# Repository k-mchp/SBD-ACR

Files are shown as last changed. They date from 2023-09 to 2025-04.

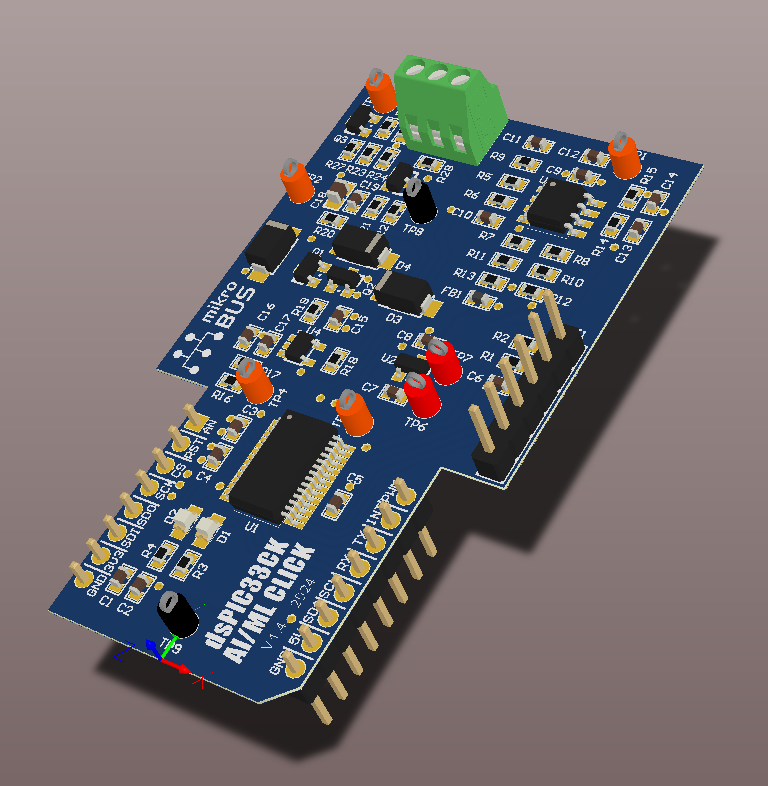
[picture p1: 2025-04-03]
PCB-Battery-click/Altium/3D Image of PCB.PNG

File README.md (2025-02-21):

#Battery Impedance Measurement Project / AC Internal Resistance
This repo contains SW flow chart and source code for Lithium Ion battery Impedance measurement project

-ACR Firmware Flow.pdf
  PDF form of current SW flow chart
  (current version = 1.2)
  
-ACR Firmware Flow.vsdx
   Visio format file of current SW flow chart
   (current version = 1.2)
   
-ACR_8-5-source.zip
  Compressed folder of MPLAB project Source code and data spreadsheet
  
-AIML-motors1
  PDF to show next step implementation of AIML control of motor to be driven by the Battery

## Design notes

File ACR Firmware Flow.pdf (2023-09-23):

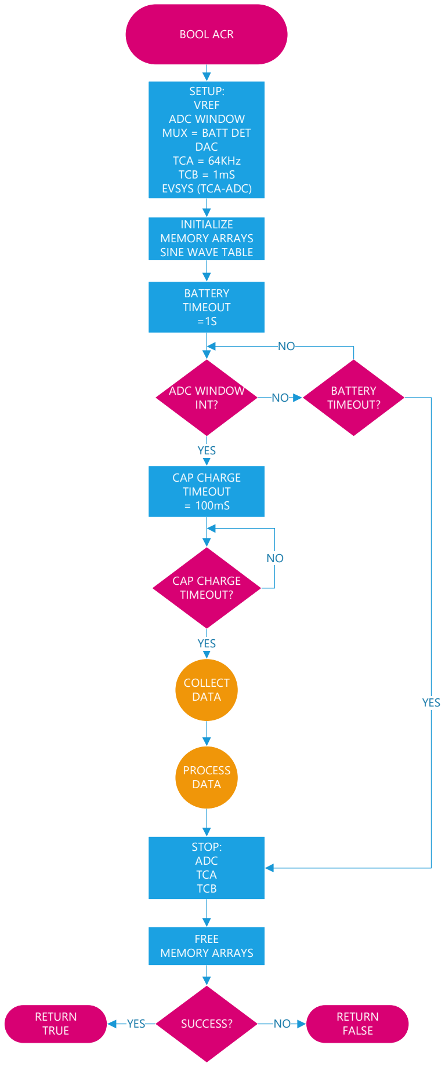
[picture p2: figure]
BOOL ACR; SETUP: VREF ADC WINDOW MUX = BATT DET DAC TCA = 64KHz TCB = 1mS EVSYS (TCA-ADC); INITIALIZE MEMORY ARRAYS SINE WAVE TABLE; BATTERY TIMEOUT =1S; ADC WINDOW INT?; SUCCESS?; RETURN; FALSE; TRUE; YES; CAP CHARGE TIMEOUT = 100mS; BATTERY TIMEOUT? NO; STOP: ADC TCA TCB; FREE MEMORY ARRAYS; CAP CHARGE TIMEOUT?; COLLECT DATA; PROCESS DATA
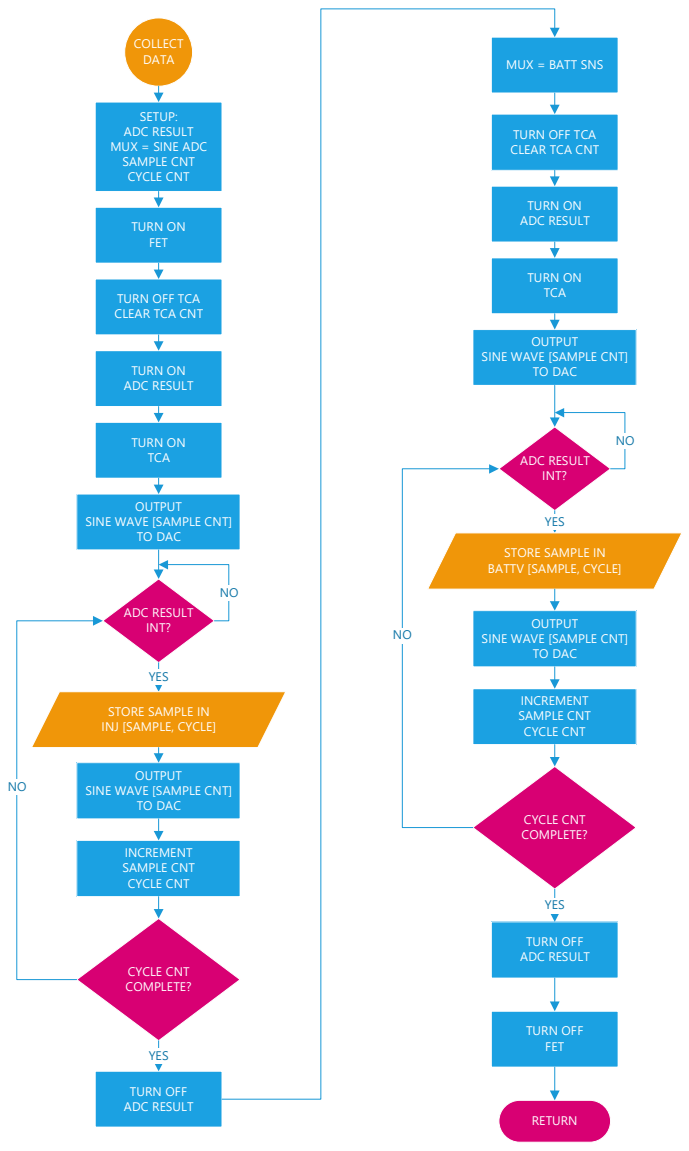
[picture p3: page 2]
COLLECT DATA; TURN ON ADC RESULT; CYCLE CNT COMPLETE?; TURN ON TCA; OUTPUT; TO DAC; TURN OFF ADC RESULT; TURN ON FET; ADC RESULT INT?; YES

MUX = BATT SNS

SETUP:
ADC RESULT
MUX = SINE ADC
SAMPLE CNT
CYCLE CNT

TURN OFF TCA
CLEAR TCA CNT

SINE WAVE [SAMPLE CNT]

STORE SAMPLE IN
BATTV [SAMPLE, CYCLE]

SINE WAVE [SAMPLE CNT] | OUTPUT TO DAC

YES

INCREMENT SAMPLE CNT CYCLE CNT

INJ [SAMPLE, CYCLE]

TURN OFF FET

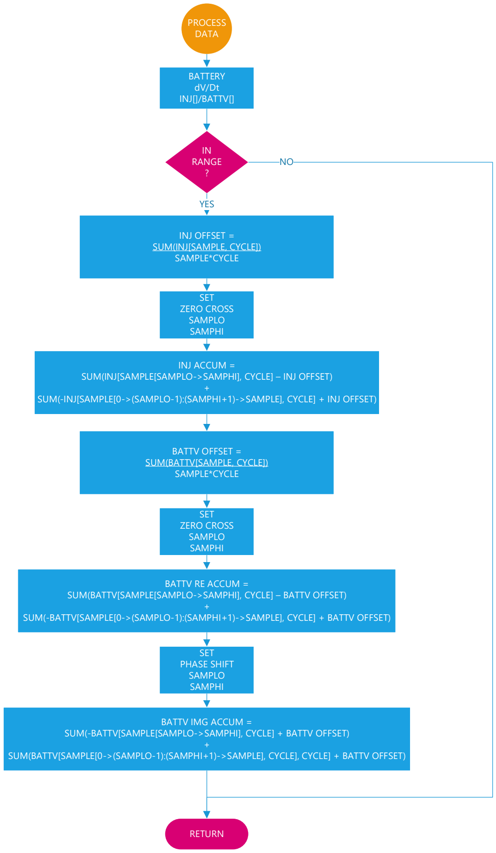
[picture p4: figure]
PROCESS DATA; BATTERY dV/Dt INJ[]/BATTV[]; IN RANGE ?; INJ OFFSET = SUM(INJ[SAMPLE, CYCLE]) SAMPLE*CYCLE; INJ ACCUM = SUM(INJ[SAMPLE[SAMPLO->SAMPHI], CYCLE] – INJ OFFSET) + SUM(-INJ[SAMPLE[0->(SAMPLO-1):(SAMPHI+1)->SAMPLE], CYCLE] + INJ OFFSET); BATTV OFFSET = SUM(BATTV[SAMPLE, CYCLE]) SAMPLE*CYCLE; BATTV RE; ACCUM =; SUM(BATTV[SAMPLE[SAMPLO->SAMPHI], CYCLE] – BATTV OFFSET) + SUM(-BATTV[SAMPLE[0->(SAMPLO-1):(SAMPHI+1)->SAMPLE], CYCLE] + BATTV OFFSET); BATTV IMG; SUM(-BATTV[SAMPLE[SAMPLO->SAMPHI], CYCLE] + BATTV OFFSET) +; YES; SET ZERO CROSS SAMPLO SAMPHI; SET; PHASE; SHIFT; SAMPLO SAMPHI

SUM(BATTV[SAMPLE[0->(SAMPLO-1):(SAMPHI+1)->SAMPLE], CYCLE], CYCLE] + BATTV OFFSET)

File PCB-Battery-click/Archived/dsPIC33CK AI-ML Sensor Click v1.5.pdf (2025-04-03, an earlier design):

1 3 2

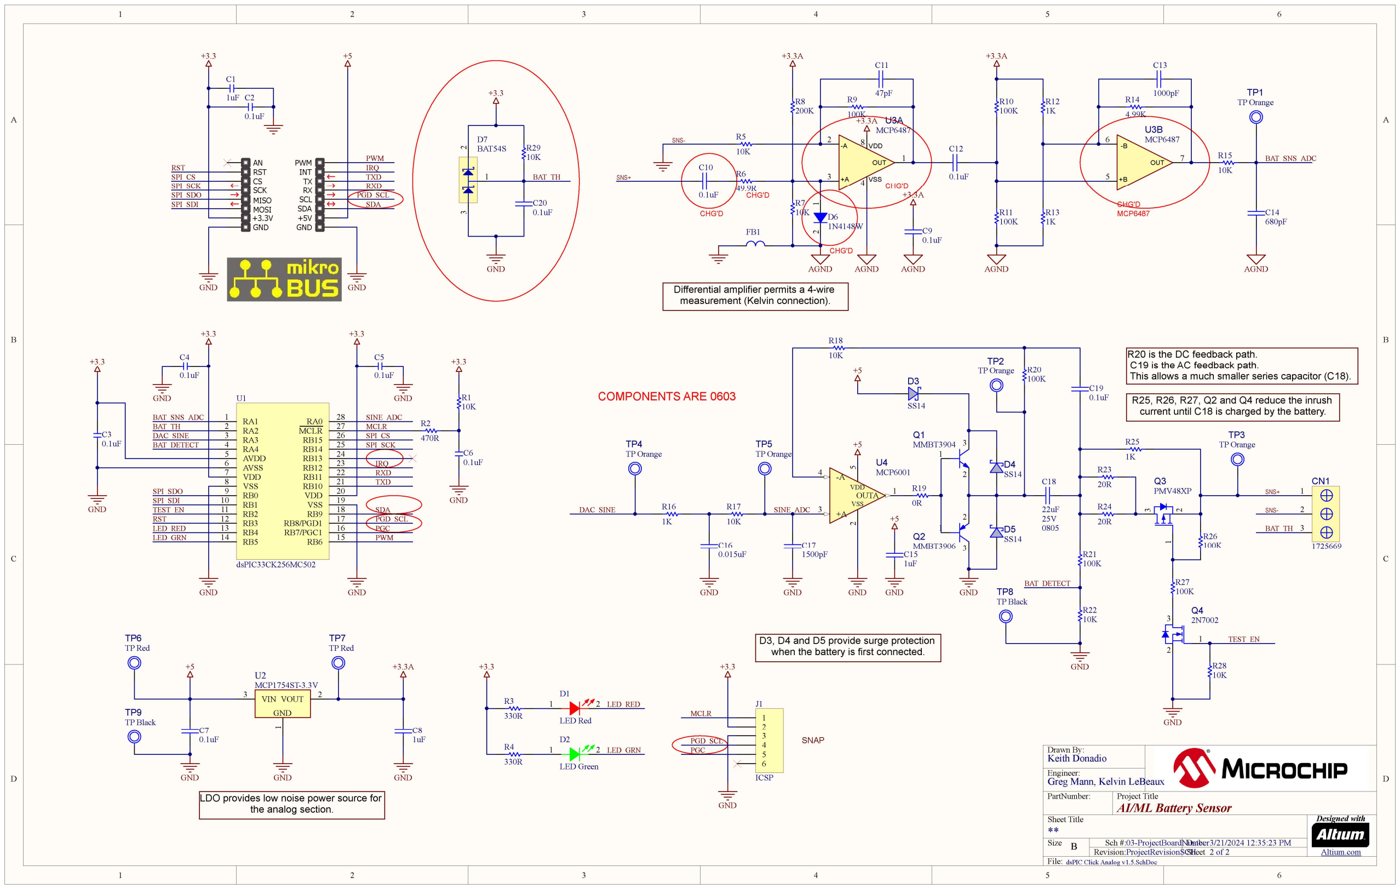
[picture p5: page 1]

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
### 2 of 2

## AI/ML Battery Sensor

3/21/2024 12:35:23 PM

dsPIC Click Analog v1.5.SchDoc

Project Title

Sch #: | Date:

File:

Revision: | Sheet

Designed with

Drawn By:

## Keith Donadio

Sheet Title
**

Engineer:

## Greg Mann, Kelvin LeBeaux

03-ProjectBoardNumber
ProjectRevisionSCH

Size B

PartNumber:

Altium.com

SNS-

GND

+5

GND

+5

+5

GND | GND

AGND

SNS+

SNS-

AGND

+3.3A

AGND

GND

+5

GND

+3.3A

GND

+3.3A

AGND

+3.3A

AGND

GND

GND

SINE_ADC

BAT_SNS_ADC

DAC_SINE

BAT_DETECT

D3, D4 and D5 provide surge protection | TEST_EN
when the battery is first connected.

### R25, R26, R27, Q2 and Q4 reduce the inrush

current until C18 is charged by the battery.

R20 is the DC feedback path.
C19 is the AC feedback path.
This allows a much smaller series capacitor (C18).

### Differential amplifier permits a 4-wire

measurement (Kelvin connection).

### LDO provides low noise power source for

the analog section.

BAT_TH

SNS+

+3.3A

1

VIN 3 | VOUT | 2

GND

U2
MCP1754ST-3.3V

+A 3

-A 4

OUTA 1

VSS2

VDD⁵

U4
MCP6001

1

2

3

CN1

1725669

3

1
2

Q4

2N7002 ³

1

2

Q3
PMV48XP

1

3

2

Q1
MMBT3904

1

2

3

Q2
MMBT3906

D3

SS14

D4
SS14

D5
SS14
GND | GND

+3.3

RST
SPI_CS
SPI_SCK
SPI_SDO
SPI_SDI

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
MOSI

MISO

+3.3V
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
+3.3

GND

RA1 1
RA2 2
RA3 3
RA4 4
AVDD 5
AVSS 6
VDD 7
VSS 8
RB0 9
RB1 10
RB2 11
RB3 12
RB4 13
RB5 14 | RB6 | 15 RB7/PGC1 | 16 RB8/PGD1 | 17 RB9 | 18 VSS | 19 VDD | 20 RB10 | 21 RB11 | 22 RB12 | 23 RB13 | 24 RB14 | 25 RB15 | 26 MCLR | 27 RA0 | 28

U1

dsPIC33CK256MC502

+3.3

GND

SPI_SDO
SPI_SDI

PWM

TXD

RXD

+3.3

LED_RED
LED_GRN

MCLR

PGD_SCL
PGC
GND | GND
BAT_SNS_ADC | SINE_ADC

DAC_SINE
BAT_DETECT

TEST_EN

SPI_CS
SPI_SCK

+3.3

BAT_TH

RST

1 2

D2

LED Green

1 2

D1

LED Red

+3.3

LED_RED

LED_GRN

MCLR

PGC

GND

+3.3

SNAP

## COMPONENTS ARE 0603

GND

GND

TP Orange

TP1

TP Orange

TP2

TP Orange

TP3

TP Orange

TP4
TP Orange

TP5

TP Red

TP6
TP Red

TP7

TP Black

TP9

TP Black

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
ICSP

25V
0805

C18

22uF

C7
0.1uF

C8
1uF

C3
0.1uF

C4

0.1uF

C5

0.1uF

C6
0.1uF

C1

1uF C2

0.1uF

C10

0.1uF

C9
0.1uF

C11

47pF

C12

0.1uF

C13

1000pF

C14
680pF

C15
1uF

C16
0.015uF

C17
1500pF

C19
R1 | 0.1uF
10K

R2
470R

R3
330R

R4
330R

R5
10K

R6
49.9R
R7
10K

R8
200K

R9
100K

R10
100K

R11
100K

R12
1K

R13
1K

R14
4.99K

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
100K

R21
100K

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
100K

R27
100K

R28
10K

CHG'D

CHG'D

CHG'D

CHG'D

CHG'D
MCP6487

C20
0.1uF

R29
10K

+3.3

GND

BAT_TH | 3

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
MCP6487

5

6

### 7 OUT

-B

+B

U3B
MCP6487 1 2

D6
1N4148W

SDA

IRQ

PGD_SCL

PGD_SCL

D7
BAT54S

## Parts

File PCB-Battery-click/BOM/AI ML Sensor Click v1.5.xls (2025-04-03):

Qty. | Designator | Description | Package | Mfg. | Mfg. Part Number | Unit/100 | Total | Notes
1 | U1 | Microcontroller, 256K FLASH | SSOP-28 | Microchip | dsPIC33CK256MC502-I/SS | $2.150 | $2.15
1 | U2 | LDO, 3.3V, 250mA | SOT-23 | Microchip | MCP1754ST-33002E/CB | $0.420 | $0.42
1 | U3 | Op Amp, Dual, 10MHz, 5V | SO-8 | Microchip | MCP6487-I/SN | $0.310 | $0.31
1 | U4 | Op Amp, Single, 1MHz, 5V | TSOP-5 | Microchip | MCP6001T-I/OT | $0.220 | $0.22
1 | D1 | LED, Red | LTST-C171 | Lite On | LTST-C171KRKT | $0.066 | $0.07
1 | D2 | LED, Green | LTST-C171 | Lite On | LTST-C171KGKT | $0.068 | $0.07
3 | D3, D4, D5 | Schottky Diode, 40V, 1A | SMA | ON Semi | SS14 | $0.117 | $0.35
1 | D6 | Diode, Switchiing, 100V, 300mA | SOD-123 | Diodes Inc | 1N4148W-7-F | $0.046 | $0.05
1 | D7 | Diode, Schottky, Dual, Series, 30V, 200mA | SOT-23 | ON Semi | BAT54SLT1G | $0.045 | $0.04
1 | Q1 | Transistor, NPN, 60V, 200mA | SOT-23 | ON Semi | MMBT3904LT3G | $0.038 | $0.04
1 | Q2 | Transistor, PNP, 40V, 200mA | SOT-23 | ON Semi | MMBT3906LT3G | $0.036 | $0.04
1 | Q3 | MOSFET, P-Channel, 20V, 4A. 55mΩ | SOT-23 | Nexperia | PMV48XPA2R | $0.154 | $0.15
1 | Q4 | N-Channel MOSFET, 60V, 310mA | SOT-23 | ON Semi | 2N7002ET7G | $0.058 | $0.06
3 | C1, C8, C15 | Capacitor, Ceramic, 1uF, 16V, X7R | 603 | Kemet | C0603C105K4RACTU | $0.024 | $0.07
11 | C2, C3, C4, C5, C6, C7, C9, C10, C12, C19, C20 | Capacitor, Ceramic, 0.1uF, 25V, X7R | 603 | Kemet | C0603C104J3RACTU | $0.028 | $0.31
1 | C11 | Capacitor, Ceramic, 47pF, 50V, C0G | 603 | Kemet | C0603C470K5GACTU | $0.019 | $0.02
1 | C13 | Capacitor, Ceramic, 1000pF, 16V, X7R | 603 | Kemet | C0603C102K4RACTU | $0.019 | $0.02
1 | C14 | Capacitor, Ceramic, 680pF, 50V, X7R | 603 | Kemet | C0603C681K5RACTU | $0.011 | $0.01
1 | C16 | Capacitor, Ceramic, 0.015uF, 50V, X7R | 603 | Kemet | C0603C153K5RACTU | $0.015 | $0.01
1 | C17 | Capacitor , Ceramic, 1500pF, 50V, X7R | 603 | Kemet | C0603C152K5RACTU | $0.012 | $0.01
1 | C18 | Capacitor, Ceramic, 22uF, 25V, X7R | 805 | Samsung | CL21A226MAYNNNE | $0.070 | $0.07
9 | R1, R5, R7, R15, R17, R18, R22, R28, R29 | Resistor, 10K Ohm, 1% | 603 | Vishay | CRCW060310K0FKEA | $0.010 | $0.09
1 | R2 | Resistor, 470 Ohm 5% | 603 | Vishay | CRCW0603470RJNEA | $0.009 | $0.01
2 | R3, R4 | Resistor, 330 Ohm 5% | 603 | Vishay | CRCW0603330RJNEA | $0.008 | $0.02
1 | R6 | Resistor, 49.9 Ohm 1% | 603 | Vishay | CRCW060349R9FKEA | $0.008 | $0.01
1 | R8 | Resistor, 200K Ohm 1% | 603 | Vishay | CRCW0603200KFKEA | $0.010 | $0.01
7 | R9, R10, R11, R20, R21, R26, R27 | Resistor, 100K Ohm, 1% | 603 | Vishay | CRCW0603100KFKEA | $0.010 | $0.07
4 | R12, R13, R16, R25 | Resistor, 1K Ohm 1% | 603 | Vishay | CRCW06031K00FKEA | $0.014 | $0.06
1 | R14 | Resistor, 4.99K Ohm 1% | 603 | Vishay | CRCW06034K99FKEA | $0.010 | $0.01
1 | R19 | Resistor, 0 Ohm 1% | 603 | Vishay | CRCW06030000Z0ED | $0.011 | $0.01
2 | R23, R24 | Resistor, 20 Ohm 1% | 603 | Vishay | CRCW060320R0FKEA | $0.010 | $0.02
1 | FB1 | Ferrite Bead, 120Ω, 500mA, 300mΩ DCR | 603 | Murata | BLM18BB121SN1D | $0.035 | $0.04
5 | TP1, TP2, TP3, TP4, TP5 | Test Point, Orange | TH | Keystone | 5003 | $0.277 | $1.39
2 | TP6, TP7 | Test Point, Red | TH | Keystone | 5000 | $0.283 | $0.57
2 | TP8, TP9 | Test Point, Black | TH | Keystone | 5001 | $0.304 | $0.61
1 | CN1 | Terminal Block, 3 Position, 2.54mm | TH | Phoenix | 1725669 | $2.190 | $2.19
1 | J1 | Header, 1x6, 2.54mm | TH | Harwin | M20-9990645 | $0.228 | $0.23
2 | MIKROBUS CONNECTOR? | Header, 1x8, 2.54mm | TH | Harwin | M20-9990845 | $0.304 | $0.61
 |  |  |  |  |  | TOTAL | $7.84

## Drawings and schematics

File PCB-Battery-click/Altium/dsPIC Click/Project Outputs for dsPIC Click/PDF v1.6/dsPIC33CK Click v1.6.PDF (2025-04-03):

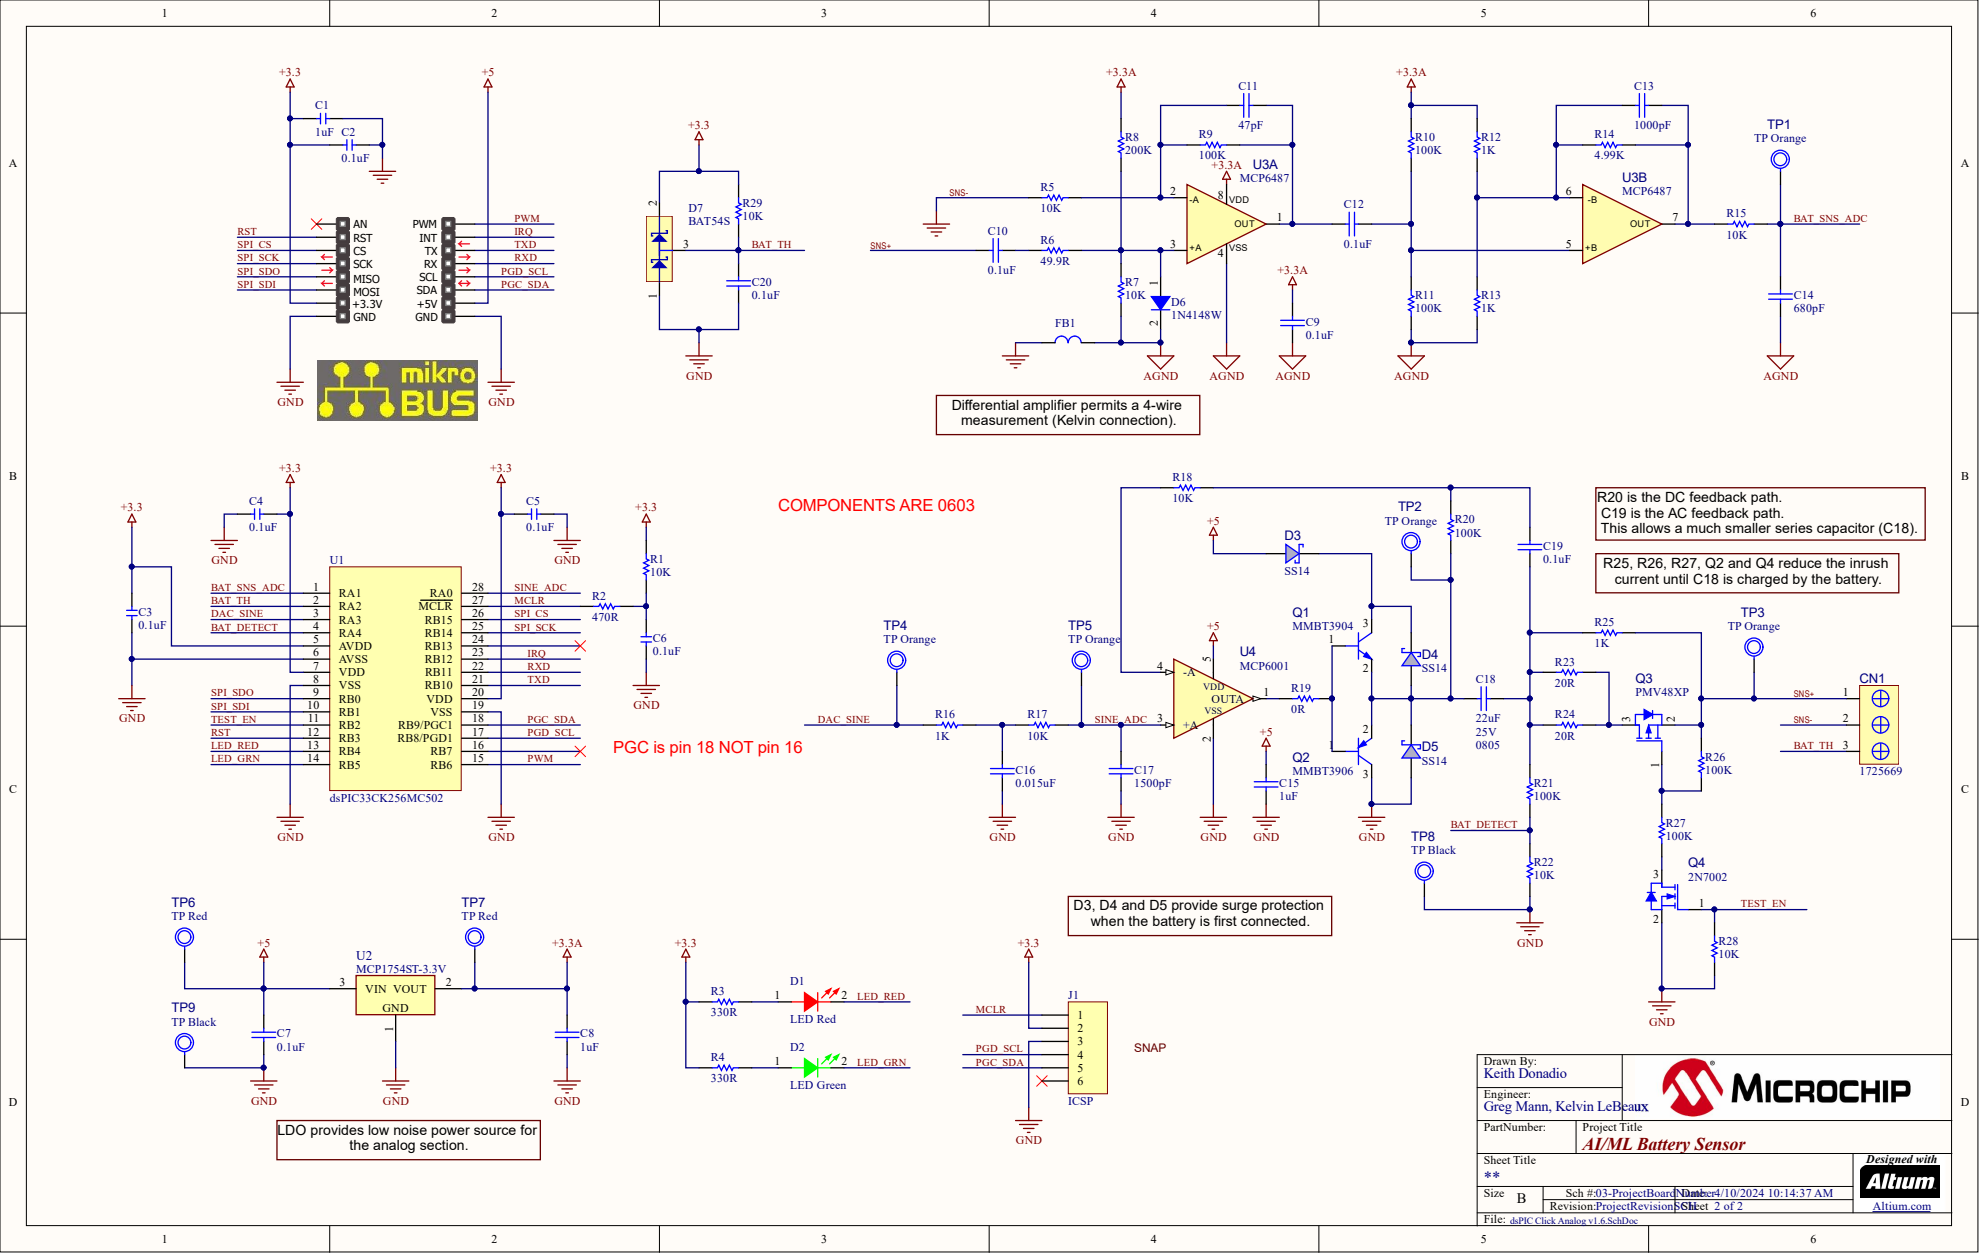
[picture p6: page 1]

Differential amplifier permits a 4-wire
measurement (Kelvin connection).

R20 is the DC feedback path.
C19 is the AC feedback path.
This allows a much smaller series capacitor (C18).

R25, R26, R27, Q2 and Q4 reduce the inrush
current until C18 is charged by the battery.

PGC is pin 18 NOT pin 16

when the battery is first connected.

Engineer:
Greg Mann, Kelvin LeBeaux

LDO provides low noise power source for

Project Title
AI/ML Battery Sensor

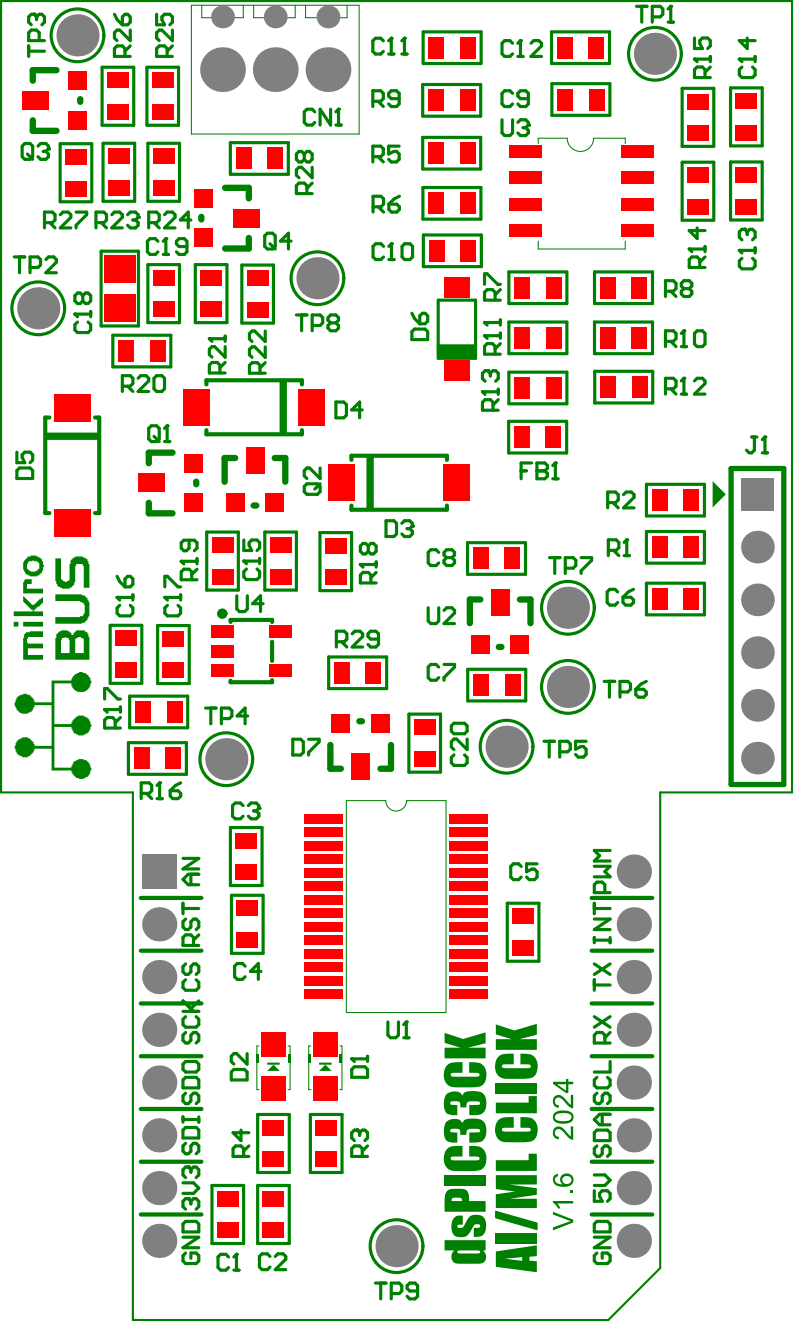
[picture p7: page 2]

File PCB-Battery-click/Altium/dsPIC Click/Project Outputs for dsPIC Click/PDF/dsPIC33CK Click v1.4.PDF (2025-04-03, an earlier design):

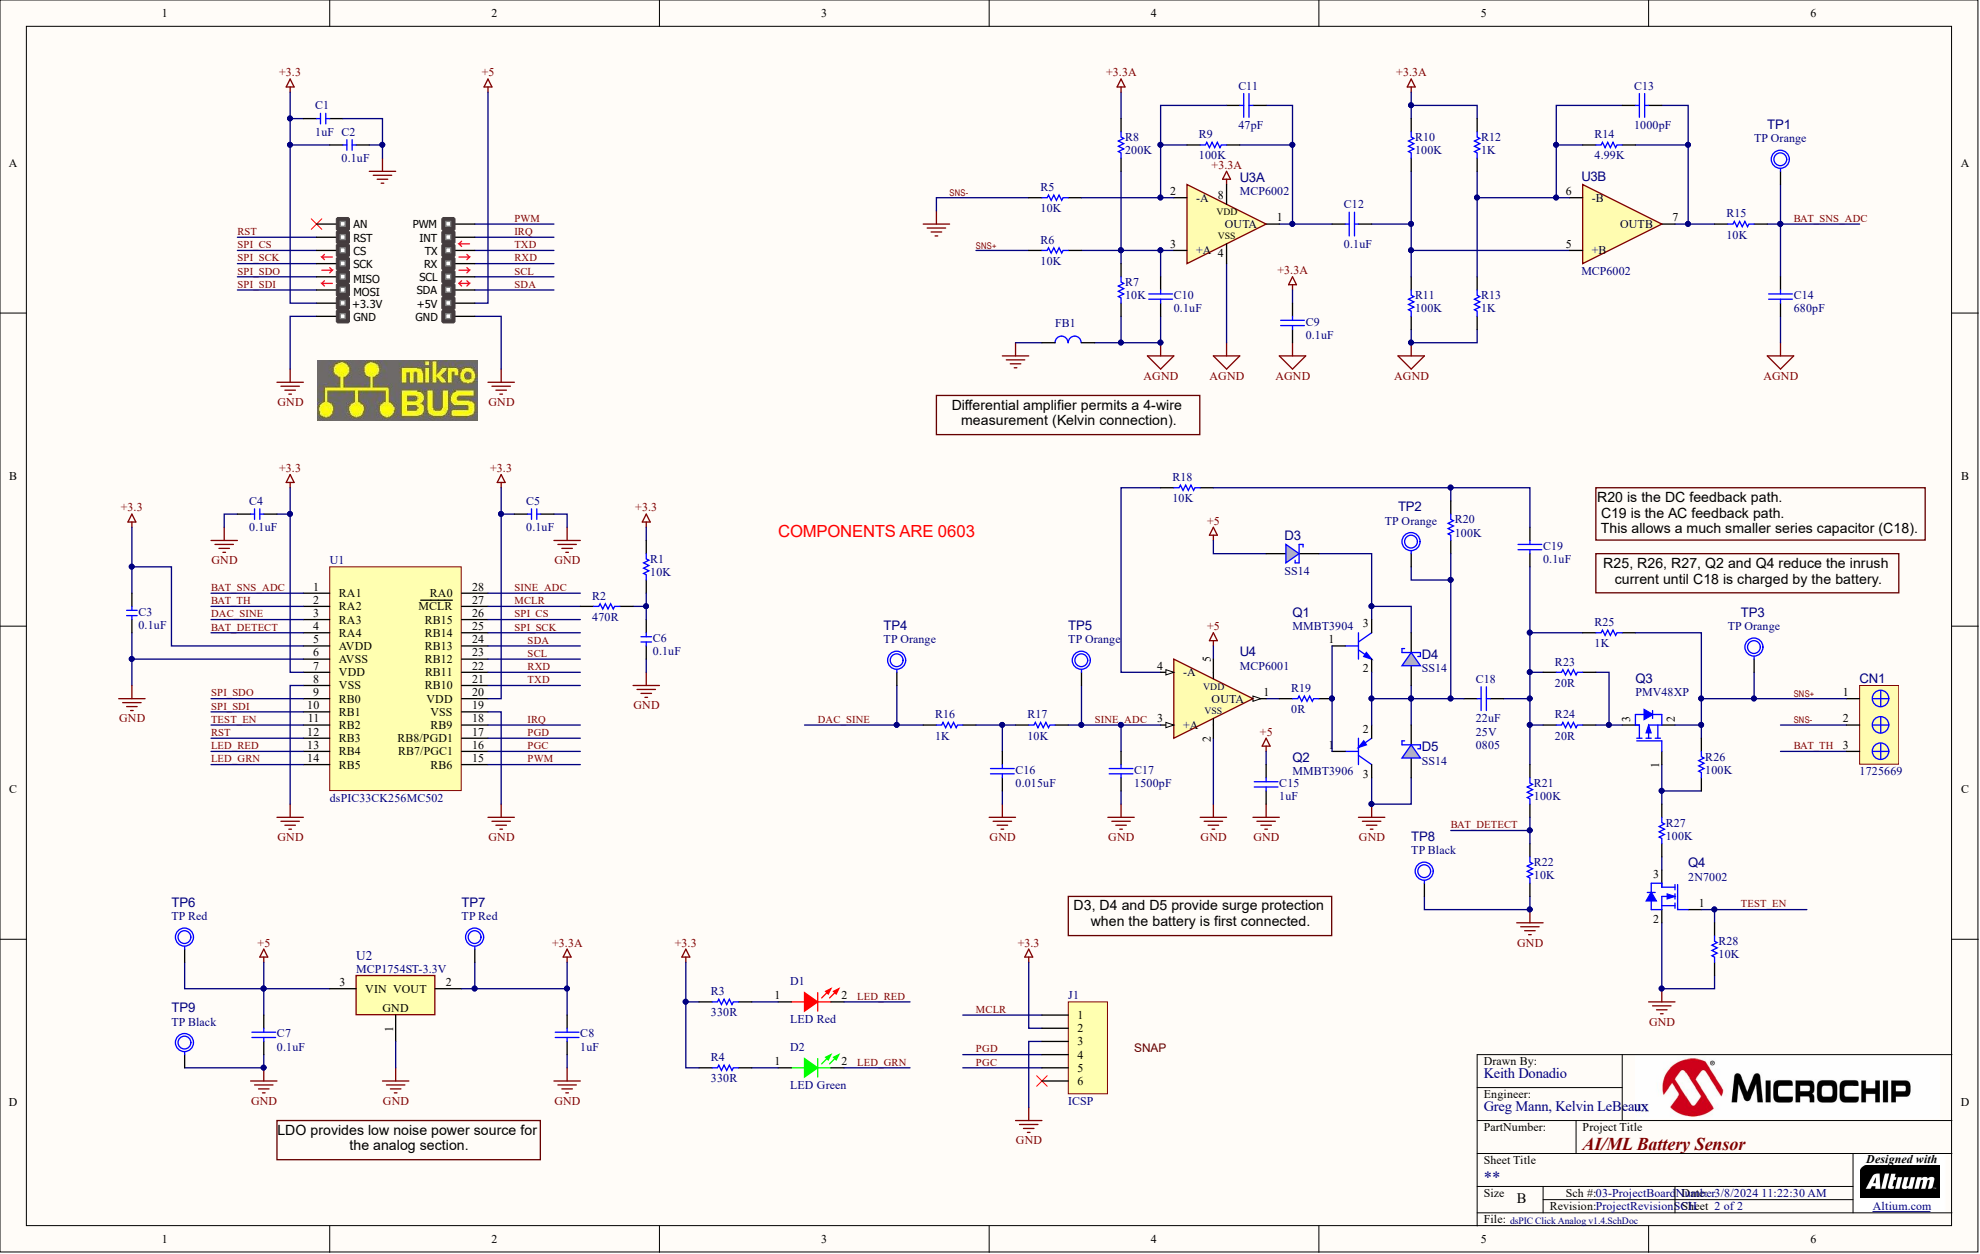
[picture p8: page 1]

Differential amplifier permits a 4-wire
measurement (Kelvin connection).

R20 is the DC feedback path.
C19 is the AC feedback path.
This allows a much smaller series capacitor (C18).

R25, R26, R27, Q2 and Q4 reduce the inrush
current until C18 is charged by the battery.

when the battery is first connected.

Engineer:
Greg Mann, Kelvin LeBeaux

LDO provides low noise power source for

Project Title
AI/ML Battery Sensor

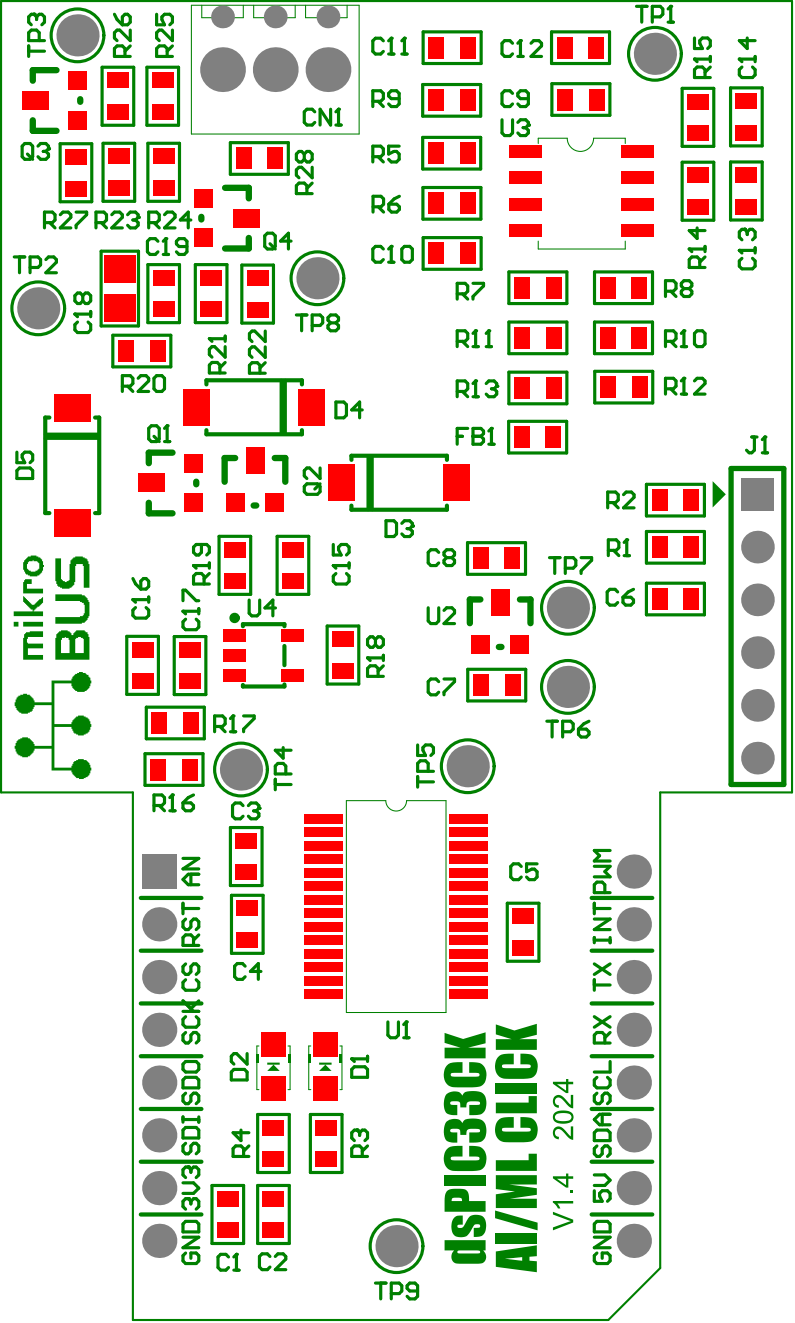
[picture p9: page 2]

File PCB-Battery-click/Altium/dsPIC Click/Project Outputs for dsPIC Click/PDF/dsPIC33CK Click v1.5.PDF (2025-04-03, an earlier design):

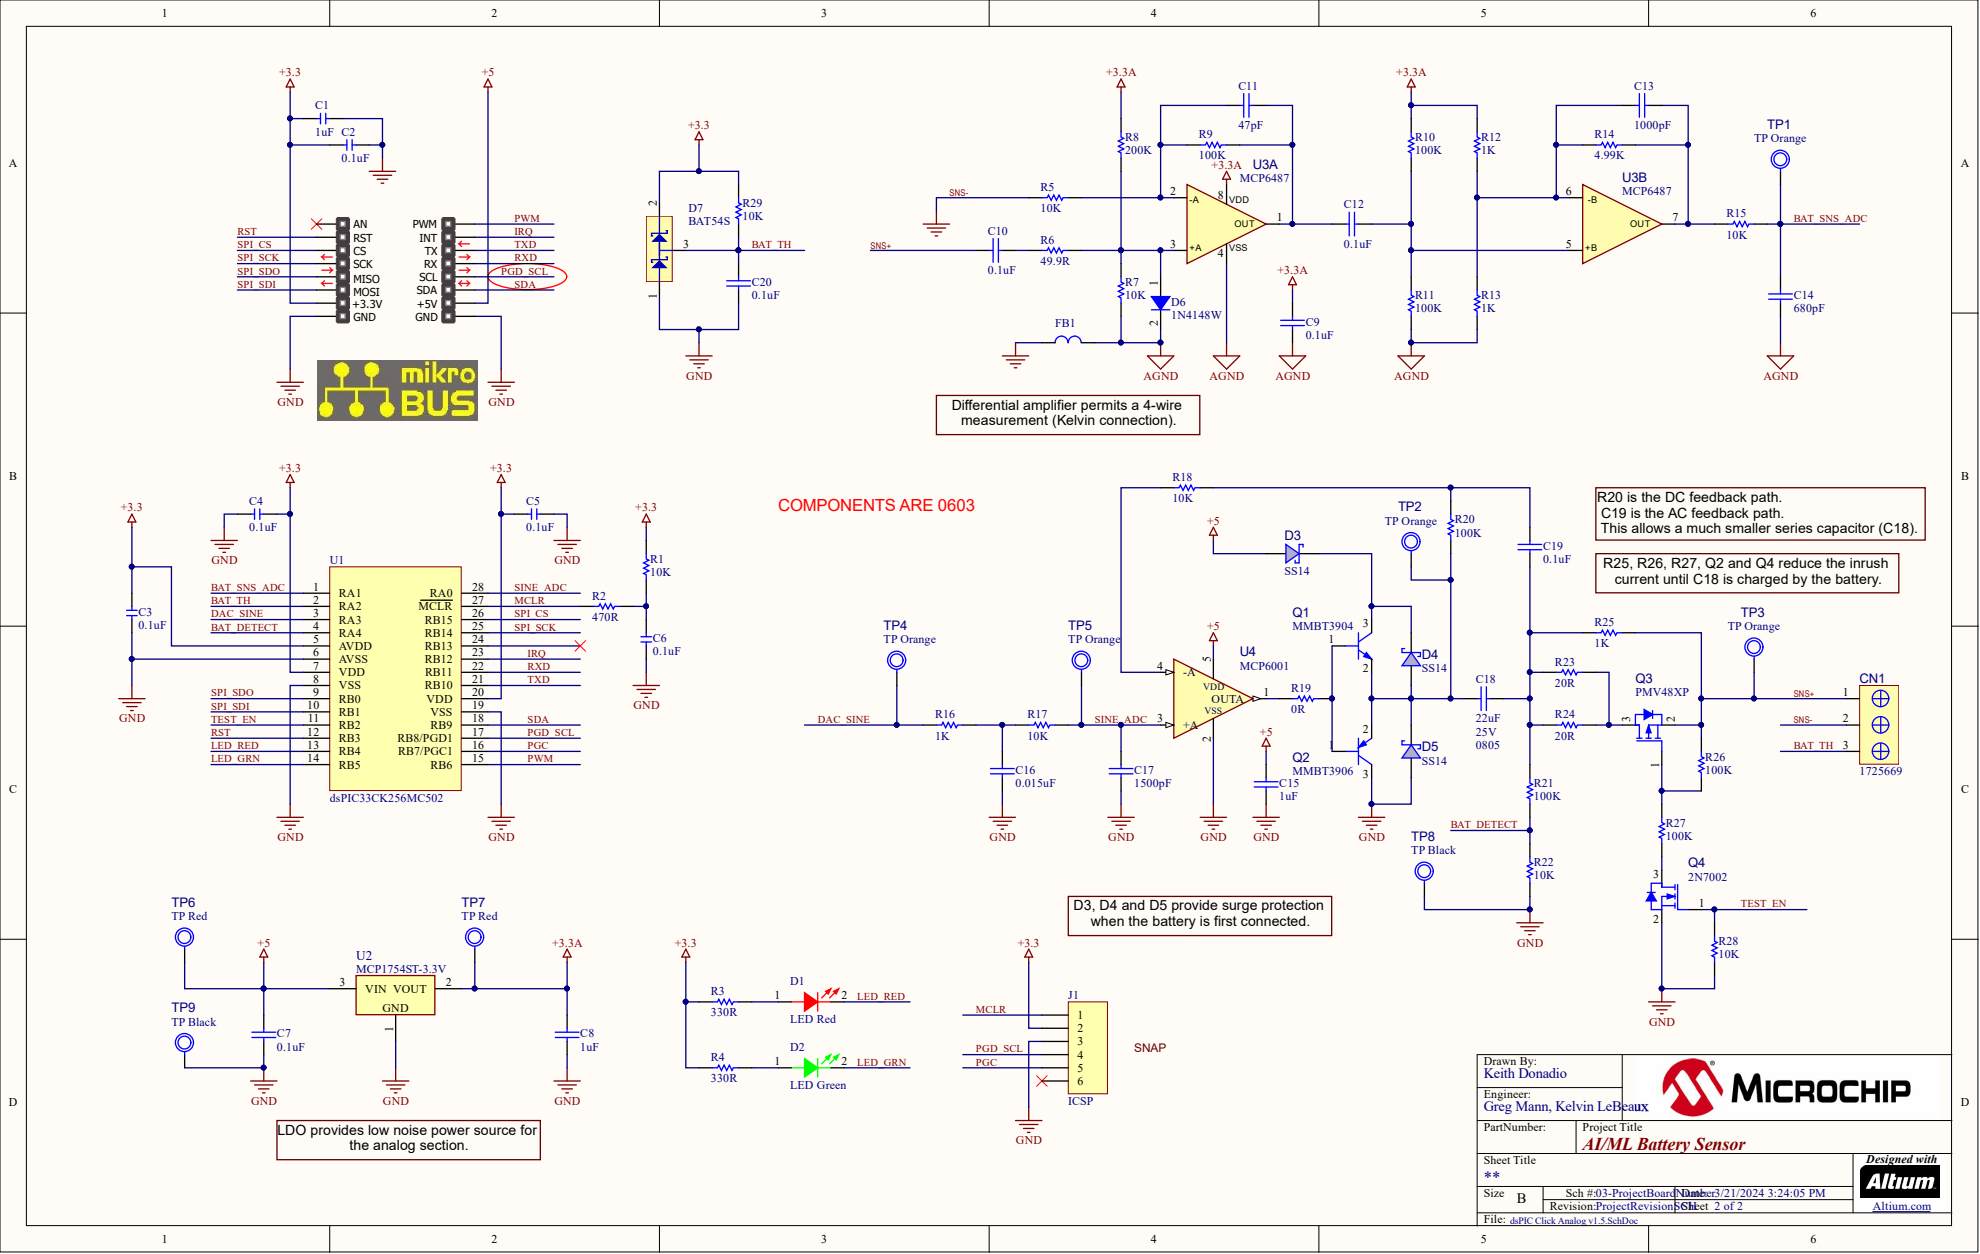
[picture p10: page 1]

Differential amplifier permits a 4-wire
measurement (Kelvin connection).

R20 is the DC feedback path.
C19 is the AC feedback path.
This allows a much smaller series capacitor (C18).

R25, R26, R27, Q2 and Q4 reduce the inrush
current until C18 is charged by the battery.

when the battery is first connected.

Engineer:
Greg Mann, Kelvin LeBeaux

LDO provides low noise power source for

Project Title
AI/ML Battery Sensor

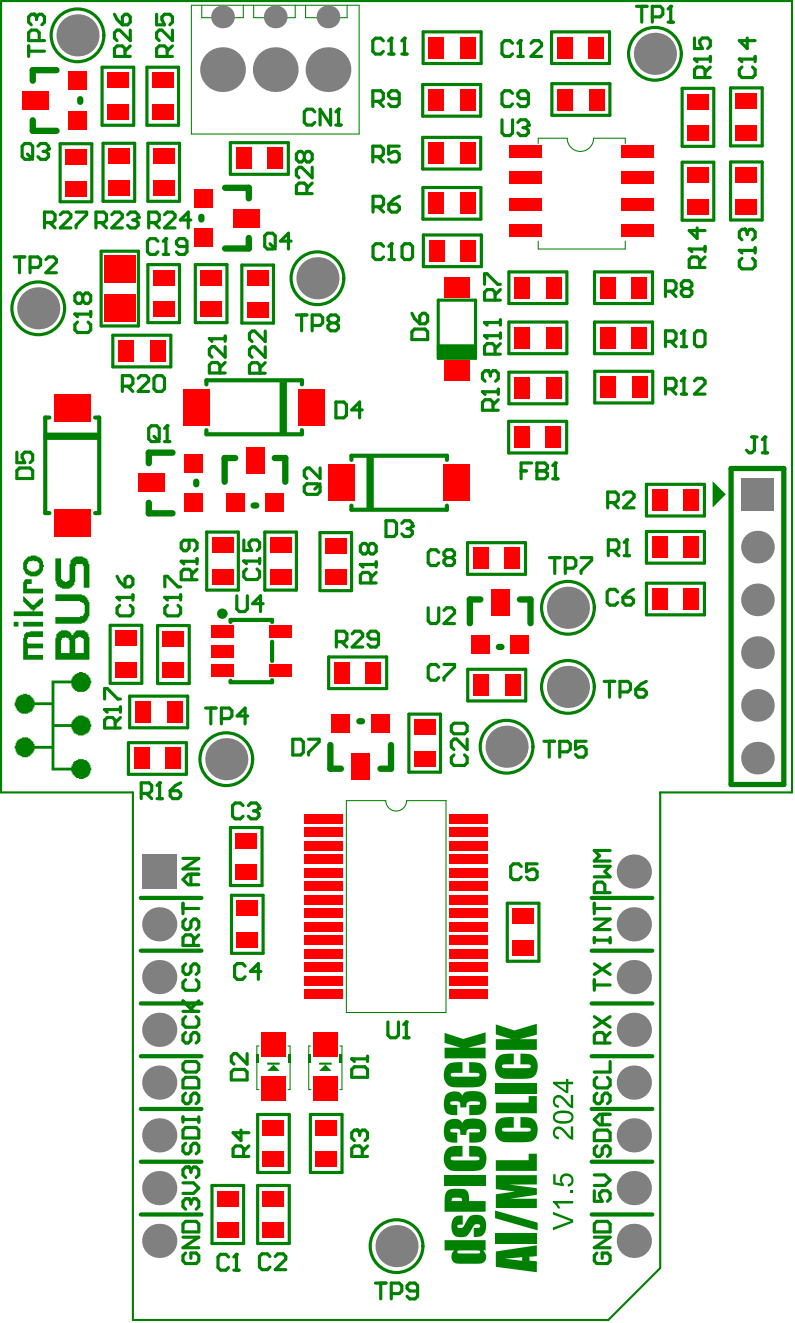
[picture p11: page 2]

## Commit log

2023-09-20 Add files via upload
    Firmware flow in pdf and Visio
2023-09-22 Updated Flow Diagram
2023-09-23 Flow diagram update
    Added clarity to the SAMPLO and SAMPHI blocks
2025-04-03 Added PCB
    Added PCB folder
    [AI ML Sensor Click v1.4.xls, AI ML Sensor Click v1.5.xls, BM70 Click SCH.SchLib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]
